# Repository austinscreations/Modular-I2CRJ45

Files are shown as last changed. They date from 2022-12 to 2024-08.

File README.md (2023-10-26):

# Modular-I2CRJ45
an oxrs compatible I2CRJ45 board in a modular format

2023-10-25 version 220 was created to fix p fet issue
also updated JLCPCB PCBa files for the modular I2CRJ45 and port PWR extention

this baord is 2 layers

port PWR is 2 layers

port PWR extention is a remote switch that allows you to turn ports on and off. the use of a 1.25mm jst cable could eb used instead, simply with pin 5 being GND connect the others to this and a port will be ON

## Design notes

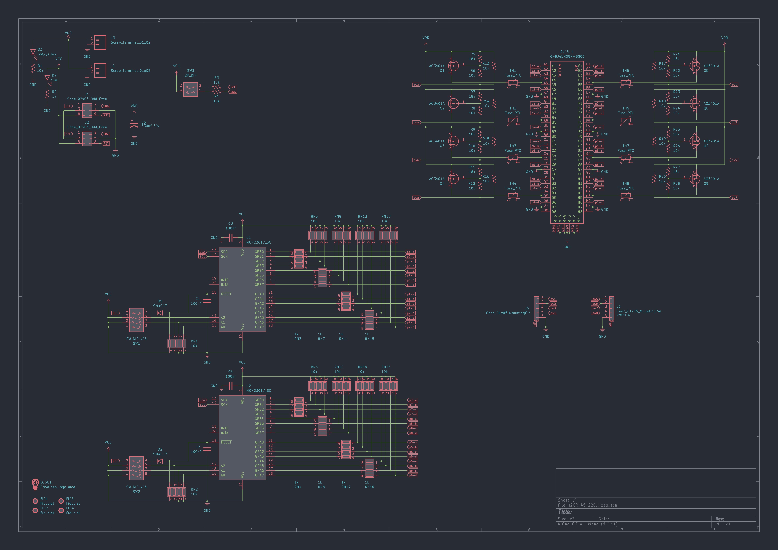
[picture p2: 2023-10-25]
rev 2_2/I2CRJ45 220 modular schematic.jpg

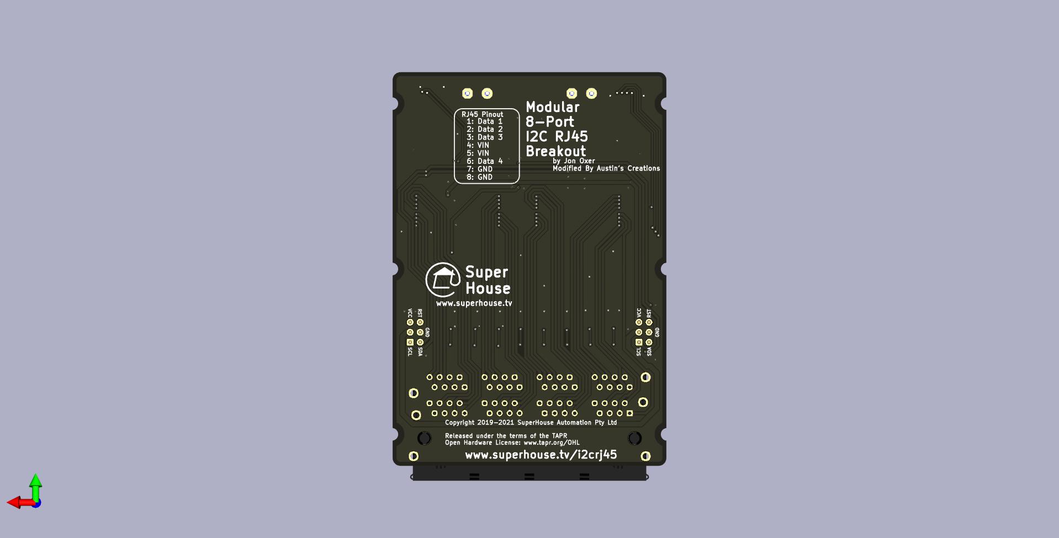
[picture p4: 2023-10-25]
rev 2_2/I2CRJ45 220 modular bottom.jpg

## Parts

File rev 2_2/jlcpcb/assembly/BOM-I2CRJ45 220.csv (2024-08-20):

Comment | Designator | Footprint | LCSC
Conn_02x03_Odd_Even | J1,J2 | IDC-Header_2x03_P2.54mm_Vertical | C132438
100nf | C1,C2,C3,C4 | C_0603_1608Metric | C14663
AO3401A | Q1,Q2,Q3,Q4,Q5,Q6,Q7,Q8 | SOT-23 | C15127
1k | RN11,RN12,RN15,RN16,RN3,RN4,RN7,RN8 | R_Array_Convex_4x0603 | C20197
1k | R2 | R_0603_1608Metric | C21190
Conn_01x05_MountingPin | J5,J6 | JST_GH_SM05B-GHS-TB_1x05-1MP_P1.25mm_Horizontal | C225114
10k | R1,R10,R12,R13,R14,R15,R16,R17,R18,R19,R20,R22,R24,R26,R28,R3,R4,R6,R8 | R_0603_1608Metric | C25804
18k | R11,R21,R23,R25,R27,R5,R7,R9 | R_0603_1608Metric | C25810
2P_DIP | SW3 | 2P_DIP | C2758181
SW_DIP_x04 | SW1,SW2 | 4P_DIP | C2758183
330uf 50v | C5 | CP_Elec_10x10 | C2895745
10k | RN1,RN10,RN13,RN14,RN17,RN18,RN2,RN5,RN6,RN9 | R_Array_Convex_4x0603 | C29718
Screw_Terminal_01x02 | J3,J4 | 2pinblock | C3703
R-RJ45R08P-8000 | RJ45-1 | R-RJ45R08P-8000 | C386760
MCP23017_SO | U1,U2 | SOIC-28W_7.5x17.9mm_P1.27mm | C47023
SM4007 | D1,D2 | D_SOD-123F | C64898
yellow | D3 | LED_0603_1608Metric | C72038
red | D4 | LED_0603_1608Metric | C2286
Fuse_PTC | TH1,TH2,TH3,TH4,TH5,TH6,TH7,TH8 | R_0603_1608Metric | C883087

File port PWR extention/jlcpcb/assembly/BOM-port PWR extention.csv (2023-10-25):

Comment | Designator | Footprint | LCSC
Conn_01x05_MountingPin | J5,J6 | JST_GH_SM05B-GHS-TB_1x05-1MP_P1.25mm_Horizontal | C225114
SW_DIP_x04 | SW1,SW2 | 4P_DIP | C2758183

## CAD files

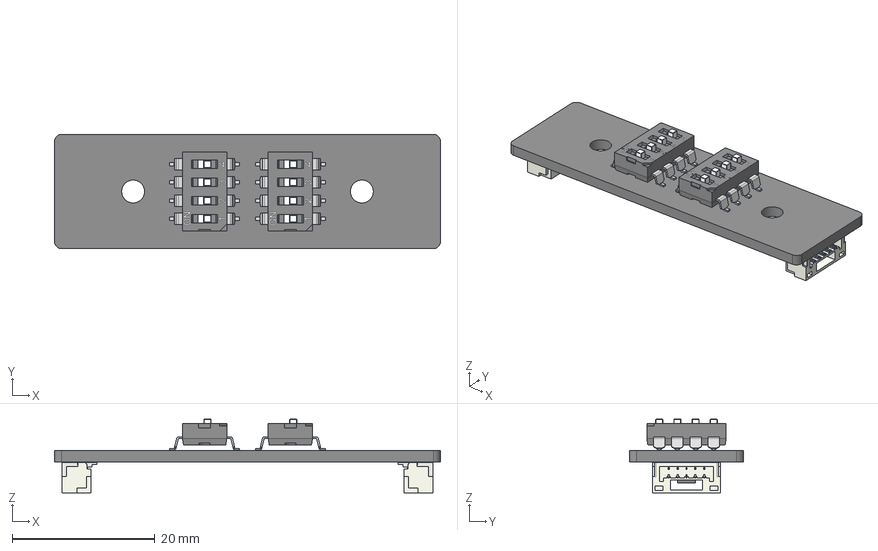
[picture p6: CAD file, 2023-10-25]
port PWR extention/port PWR extention.step
54.0 x 16.0 x 10.3 mm
_autosave-port PWR extention PCB

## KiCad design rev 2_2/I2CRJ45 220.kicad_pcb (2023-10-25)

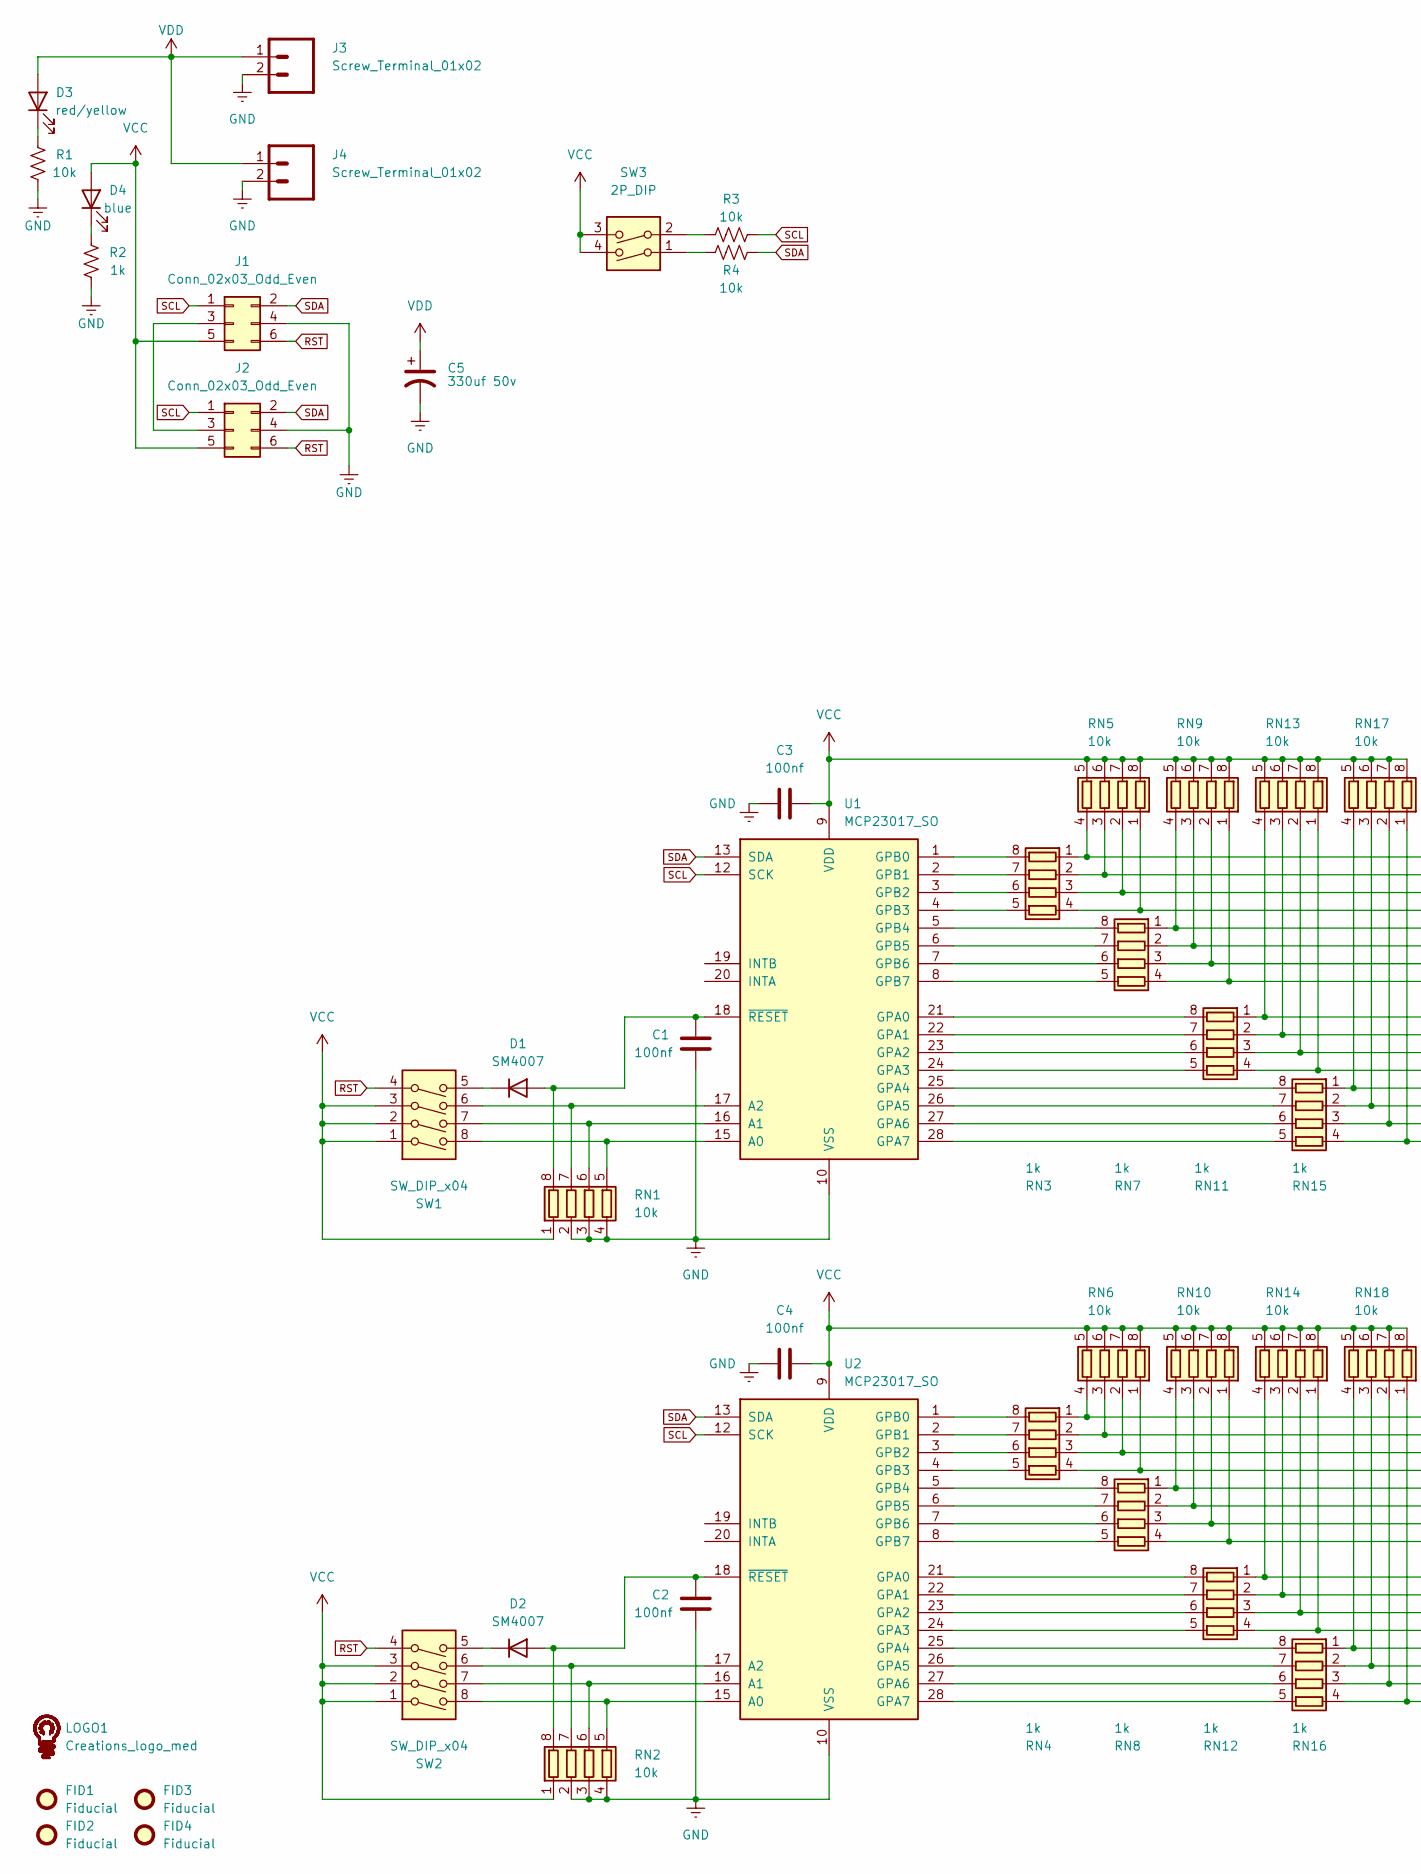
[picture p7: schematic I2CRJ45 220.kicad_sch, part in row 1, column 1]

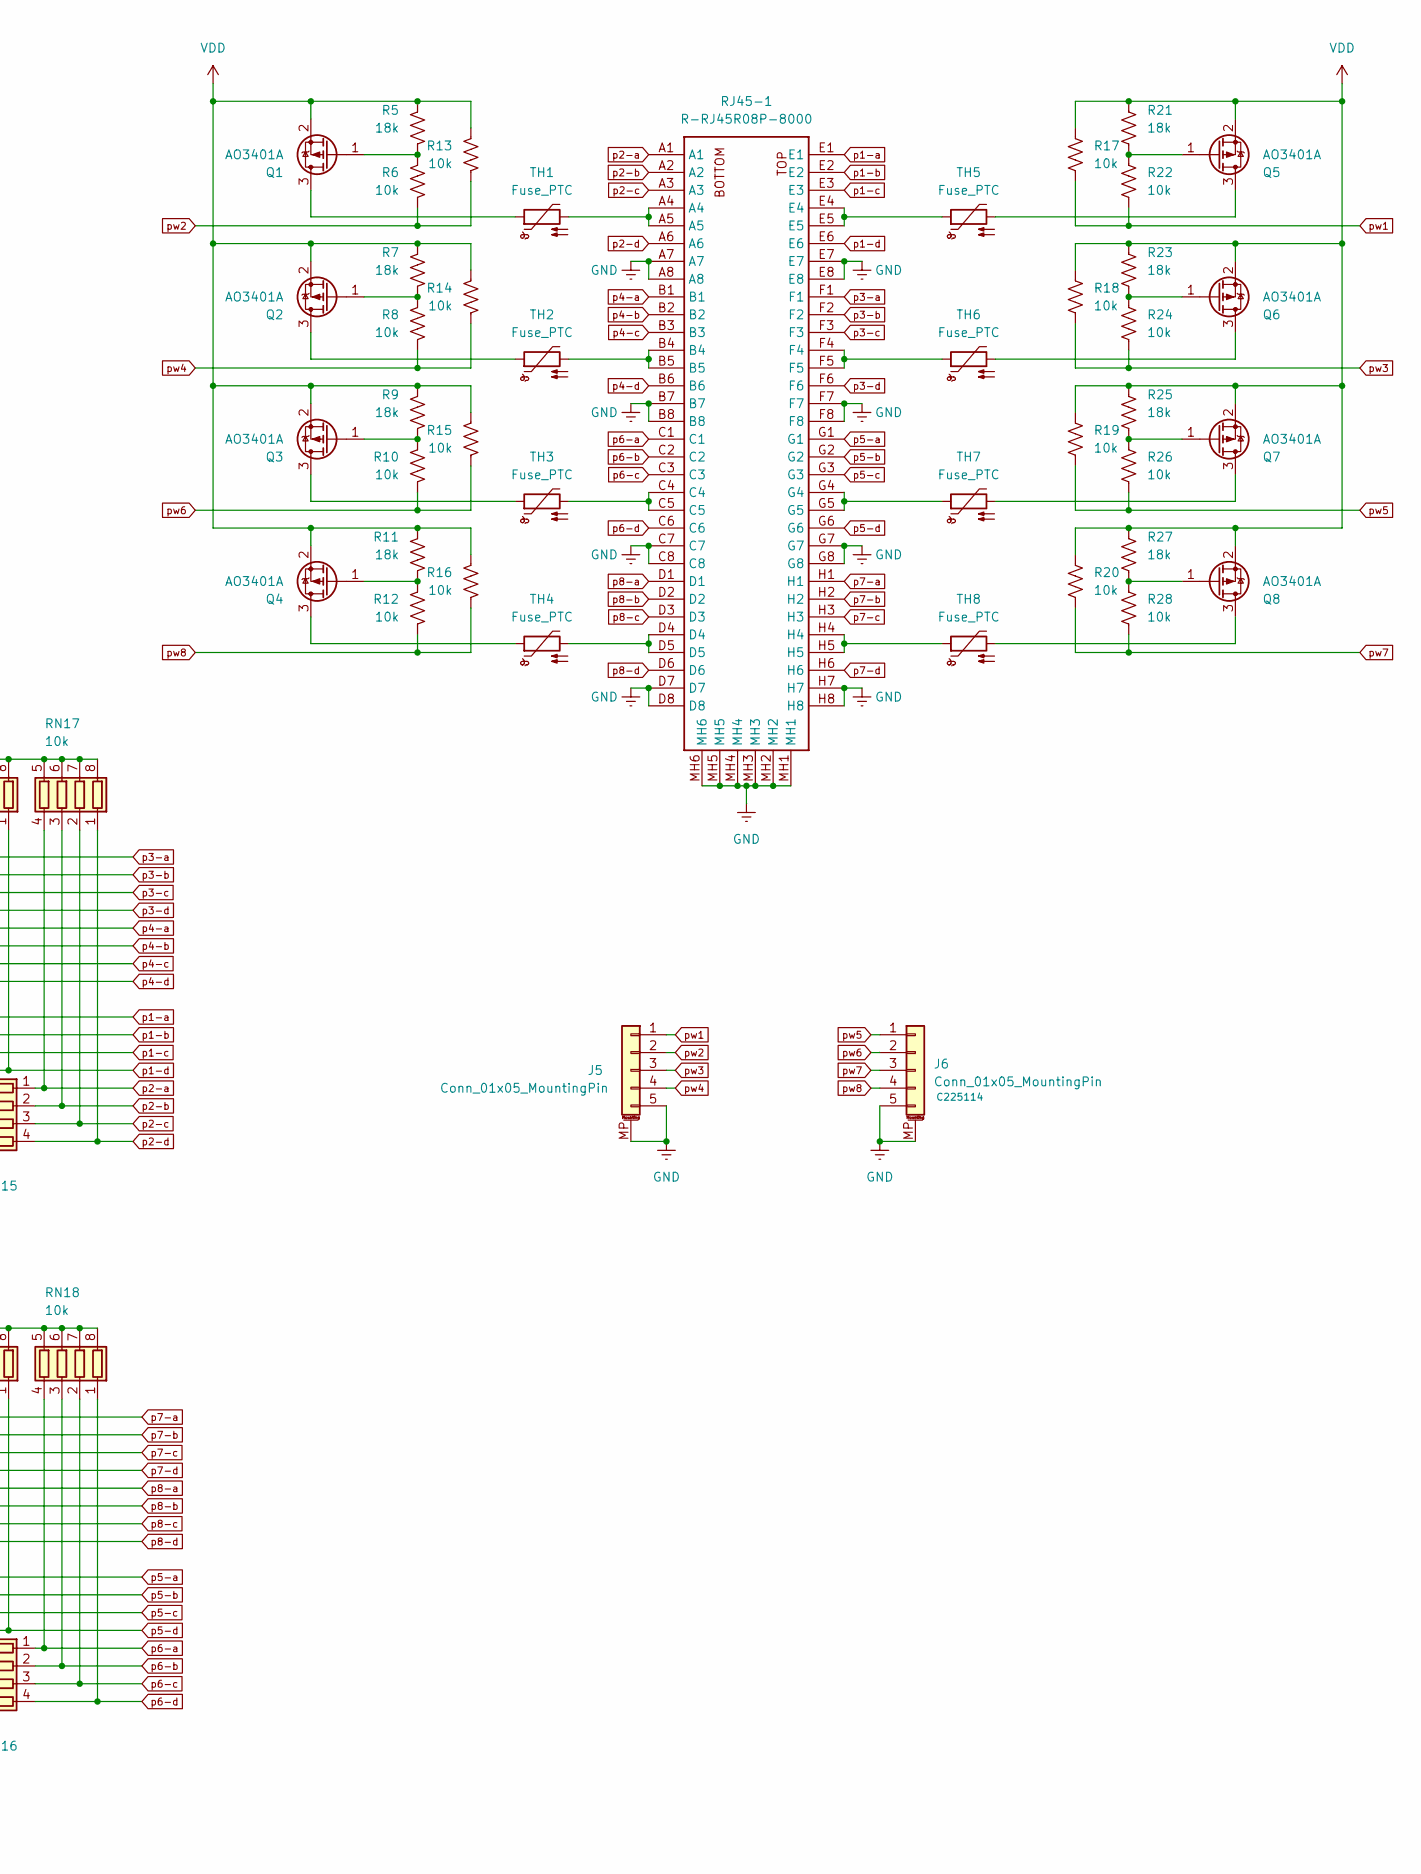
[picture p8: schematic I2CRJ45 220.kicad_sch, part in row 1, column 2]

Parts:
C1, C2, C3, C4: 100nf; C_0603_1608Metric; LCSC C14663
C5: 330uf 50v; CP_Elec_10x10; LCSC C2895745
D1, D2: SM4007; D_SOD-123F; LCSC C64898
D3: red/yellow; LED_0603_1608Metric; LCSC C72038
D4: blue; LED_0603_1608Metric; LCSC C72041
FID1, FID2, FID3, FID4: Fiducial; Fiducial_1mm_Mask2mm
J1, J2: Conn_02x03_Odd_Even; IDC-Header_2x03_P2.54mm_Vertical; LCSC C132438
J3, J4: Screw_Terminal_01x02; 2pinblock; LCSC C3703
J5, J6: Conn_01x05_MountingPin; JST_GH_SM05B-GHS-TB_1x05-1MP_P1.25mm_Horizontal; LCSC C225114
LOGO1: Creations_logo_med; Creations logo med
Q1, Q2, Q3, Q4, Q5, Q6, Q7, Q8: AO3401A; SOT-23; LCSC C15127
R1, R3, R4, R6, R8, R10, R12, R13, R14, R15, R16, R17, R18, R19, R20, R22, R24, R26, R28: 10k; R_0603_1608Metric; LCSC C25804
R2: 1k; R_0603_1608Metric; LCSC C21190
R5, R7, R9, R11, R21, R23, R25, R27: 18k; R_0603_1608Metric; LCSC C25810
RJ45-1: R-RJ45R08P-8000; LCSC C386760
RN1, RN2, RN5, RN6, RN9, RN10, RN13, RN14, RN17, RN18: 10k; R_Array_Convex_4x0603; LCSC C29718
RN3, RN4, RN7, RN8, RN11, RN12, RN15, RN16: 1k; R_Array_Convex_4x0603; LCSC C20197
SW1, SW2: SW_DIP_x04; 4P_DIP; LCSC C2758183
SW3: 2P_DIP; LCSC C2758181
TH1, TH2, TH3, TH4, TH5, TH6, TH7, TH8: Fuse_PTC; R_0603_1608Metric; LCSC C883087
U1, U2: MCP23017_SO; SOIC-28W_7.5x17.9mm_P1.27mm; LCSC C47023

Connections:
GNDREF: C1.2, C2.2, C3.1, C4.1, C5.2, J1.4, J2.4, J3.2, J4.2, J5.5, J5.MP (MountPin), J6.5, J6.MP (MountPin), R1.2, R2.2, RJ45-1.A7, RJ45-1.A8, RJ45-1.B7, RJ45-1.B8, RJ45-1.C7, RJ45-1.C8, RJ45-1.D7, RJ45-1.D8, RJ45-1.E7, RJ45-1.E8, RJ45-1.F7, RJ45-1.F8, RJ45-1.G7, RJ45-1.G8, RJ45-1.H7, RJ45-1.H8, RJ45-1.MH1, RJ45-1.MH2, RJ45-1.MH3, RJ45-1.MH4, RJ45-1.MH5, RJ45-1.MH6, RN1.2 (R2.1), RN1.3 (R3.1), RN1.4 (R4.1), RN2.2 (R2.1), RN2.3 (R3.1), RN2.4 (R4.1), U1.10 (VSS), U2.10 (VSS)
unnamed: C1.1, D1.2 (A), RN1.8 (R1.2), U1.18 (~RESET)
unnamed: C2.1, D2.2 (A), RN2.8 (R1.2), U2.18 (~RESET)
unnamed: D1.1 (K), SW1.5
unnamed: D2.1 (K), SW2.5
unnamed: D3.1 (K), R1.1
unnamed: D4.1 (K), R2.1
unnamed: J1.3, J2.3
unnamed: Q1.1 (G), R5.2, R6.1
unnamed: Q2.1 (G), R7.2, R8.1
unnamed: Q3.1 (G), R9.2, R10.1
unnamed: Q4.1 (G), R11.2, R12.1
unnamed: Q5.1 (G), R21.2, R22.1
unnamed: Q6.1 (G), R23.2, R24.1
unnamed: Q7.1 (G), R25.2, R26.1
unnamed: Q8.1 (G), R27.2, R28.1
unnamed: R3.1, SW3.2
unnamed: R4.1, SW3.1
unnamed: RJ45-1.A4, RJ45-1.A5, TH1.2
unnamed: RJ45-1.B4, RJ45-1.B5, TH2.2
unnamed: RJ45-1.C4, RJ45-1.C5, TH3.2
unnamed: RJ45-1.D4, RJ45-1.D5, TH4.2
unnamed: RJ45-1.E4, RJ45-1.E5, TH5.1
unnamed: RJ45-1.F4, RJ45-1.F5, TH6.1
unnamed: RJ45-1.G4, RJ45-1.G5, TH7.1
unnamed: RJ45-1.H4, RJ45-1.H5, TH8.1
unnamed: RN1.5 (R4.2), SW1.8, U1.15 (A0)
unnamed: RN1.6 (R3.2), SW1.7, U1.16 (A1)
unnamed: RN1.7 (R2.2), SW1.6, U1.17 (A2)
unnamed: RN2.5 (R4.2), SW2.8, U2.15 (A0)
unnamed: RN2.6 (R3.2), SW2.7, U2.16 (A1)
unnamed: RN2.7 (R2.2), SW2.6, U2.17 (A2)
unnamed: RN3.5 (R4.2), U1.4 (GPB3)
unnamed: RN3.6 (R3.2), U1.3 (GPB2)
unnamed: RN3.7 (R2.2), U1.2 (GPB1)
unnamed: RN3.8 (R1.2), U1.1 (GPB0)
unnamed: RN4.5 (R4.2), U2.4 (GPB3)
unnamed: RN4.6 (R3.2), U2.3 (GPB2)
unnamed: RN4.7 (R2.2), U2.2 (GPB1)
unnamed: RN4.8 (R1.2), U2.1 (GPB0)
unnamed: RN7.5 (R4.2), U1.8 (GPB7)
unnamed: RN7.6 (R3.2), U1.7 (GPB6)
unnamed: RN7.7 (R2.2), U1.6 (GPB5)
unnamed: RN7.8 (R1.2), U1.5 (GPB4)
unnamed: RN8.5 (R4.2), U2.8 (GPB7)
unnamed: RN8.6 (R3.2), U2.7 (GPB6)
unnamed: RN8.7 (R2.2), U2.6 (GPB5)
unnamed: RN8.8 (R1.2), U2.5 (GPB4)
unnamed: RN11.5 (R4.2), U1.24 (GPA3)
unnamed: RN11.6 (R3.2), U1.23 (GPA2)
unnamed: RN11.7 (R2.2), U1.22 (GPA1)
unnamed: RN11.8 (R1.2), U1.21 (GPA0)
unnamed: RN12.5 (R4.2), U2.24 (GPA3)
unnamed: RN12.6 (R3.2), U2.23 (GPA2)
unnamed: RN12.7 (R2.2), U2.22 (GPA1)
unnamed: RN12.8 (R1.2), U2.21 (GPA0)
unnamed: RN15.5 (R4.2), U1.28 (GPA7)
unnamed: RN15.6 (R3.2), U1.27 (GPA6)
unnamed: RN15.7 (R2.2), U1.26 (GPA5)
unnamed: RN15.8 (R1.2), U1.25 (GPA4)
unnamed: RN16.5 (R4.2), U2.28 (GPA7)
unnamed: RN16.6 (R3.2), U2.27 (GPA6)
unnamed: RN16.7 (R2.2), U2.26 (GPA5)
unnamed: RN16.8 (R1.2), U2.25 (GPA4)
unnamed: Q1.3 (D), TH1.1
unnamed: Q2.3 (D), TH2.1
unnamed: Q3.3 (D), TH3.1
unnamed: Q4.3 (D), TH4.1
unnamed: Q5.3 (D), TH5.2
unnamed: Q6.3 (D), TH6.2
unnamed: Q7.3 (D), TH7.2
unnamed: Q8.3 (D), TH8.2
RST: J1.6, J2.6, SW1.4, SW2.4
SCL: J1.1, J2.1, R3.2, U1.12 (SCK), U2.12 (SCK)
SDA: J1.2, J2.2, R4.2, U1.13 (SDA), U2.13 (SDA)
VCC: C3.2, C4.2, D4.2 (A), J1.5, J2.5, RN1.1 (R1.1), RN2.1 (R1.1), RN5.5 (R4.2), RN5.6 (R3.2), RN5.7 (R2.2), RN5.8 (R1.2), RN6.5 (R4.2), RN6.6 (R3.2), RN6.7 (R2.2), RN6.8 (R1.2), RN9.5 (R4.2), RN9.6 (R3.2), RN9.7 (R2.2), RN9.8 (R1.2), RN10.5 (R4.2), RN10.6 (R3.2), RN10.7 (R2.2), RN10.8 (R1.2), RN13.5 (R4.2), RN13.6 (R3.2), RN13.7 (R2.2), RN13.8 (R1.2), RN14.5 (R4.2), RN14.6 (R3.2), RN14.7 (R2.2), RN14.8 (R1.2), RN17.5 (R4.2), RN17.6 (R3.2), RN17.7 (R2.2), RN17.8 (R1.2), RN18.5 (R4.2), RN18.6 (R3.2), RN18.7 (R2.2), RN18.8 (R1.2), SW1.1, SW1.2, SW1.3, SW2.1, SW2.2, SW2.3, SW3.3, SW3.4, U1.9 (VDD), U2.9 (VDD)
VDD: C5.1, D3.2 (A), J3.1, J4.1, Q1.2 (S), Q2.2 (S), Q3.2 (S), Q4.2 (S), Q5.2 (S), Q6.2 (S), Q7.2 (S), Q8.2 (S), R5.1, R7.1, R9.1, R11.1, R13.1, R14.1, R15.1, R16.1, R17.1, R18.1, R19.1, R20.1, R21.1, R23.1, R25.1, R27.1
p1-a: RJ45-1.E1, RN11.1 (R1.1), RN13.4 (R4.1)
p1-b: RJ45-1.E2, RN11.2 (R2.1), RN13.3 (R3.1)
p1-c: RJ45-1.E3, RN11.3 (R3.1), RN13.2 (R2.1)
p1-d: RJ45-1.E6, RN11.4 (R4.1), RN13.1 (R1.1)
p2-a: RJ45-1.A1, RN15.1 (R1.1), RN17.4 (R4.1)
p2-b: RJ45-1.A2, RN15.2 (R2.1), RN17.3 (R3.1)
p2-c: RJ45-1.A3, RN15.3 (R3.1), RN17.2 (R2.1)
p2-d: RJ45-1.A6, RN15.4 (R4.1), RN17.1 (R1.1)
p3-a: RJ45-1.F1, RN3.1 (R1.1), RN5.4 (R4.1)
p3-b: RJ45-1.F2, RN3.2 (R2.1), RN5.3 (R3.1)
p3-c: RJ45-1.F3, RN3.3 (R3.1), RN5.2 (R2.1)
p3-d: RJ45-1.F6, RN3.4 (R4.1), RN5.1 (R1.1)
p4-a: RJ45-1.B1, RN7.1 (R1.1), RN9.4 (R4.1)
p4-b: RJ45-1.B2, RN7.2 (R2.1), RN9.3 (R3.1)
p4-c: RJ45-1.B3, RN7.3 (R3.1), RN9.2 (R2.1)
p4-d: RJ45-1.B6, RN7.4 (R4.1), RN9.1 (R1.1)
p5-a: RJ45-1.G1, RN12.1 (R1.1), RN14.4 (R4.1)
p5-b: RJ45-1.G2, RN12.2 (R2.1), RN14.3 (R3.1)
p5-c: RJ45-1.G3, RN12.3 (R3.1), RN14.2 (R2.1)
p5-d: RJ45-1.G6, RN12.4 (R4.1), RN14.1 (R1.1)
p6-a: RJ45-1.C1, RN16.1 (R1.1), RN18.4 (R4.1)
p6-b: RJ45-1.C2, RN16.2 (R2.1), RN18.3 (R3.1)
p6-c: RJ45-1.C3, RN16.3 (R3.1), RN18.2 (R2.1)
p6-d: RJ45-1.C6, RN16.4 (R4.1), RN18.1 (R1.1)
p7-a: RJ45-1.H1, RN4.1 (R1.1), RN6.4 (R4.1)
p7-b: RJ45-1.H2, RN4.2 (R2.1), RN6.3 (R3.1)
p7-c: RJ45-1.H3, RN4.3 (R3.1), RN6.2 (R2.1)
p7-d: RJ45-1.H6, RN4.4 (R4.1), RN6.1 (R1.1)
p8-a: RJ45-1.D1, RN8.1 (R1.1), RN10.4 (R4.1)
p8-b: RJ45-1.D2, RN8.2 (R2.1), RN10.3 (R3.1)
p8-c: RJ45-1.D3, RN8.3 (R3.1), RN10.2 (R2.1)
p8-d: RJ45-1.D6, RN8.4 (R4.1), RN10.1 (R1.1)
pw1: J5.1, R17.2, R22.2
pw2: J5.2, R6.2, R13.2
pw3: J5.3, R18.2, R24.2
pw4: J5.4, R8.2, R14.2
pw5: J6.1, R19.2, R26.2
pw6: J6.2, R10.2, R15.2
pw7: J6.3, R20.2, R28.2
pw8: J6.4, R12.2, R16.2

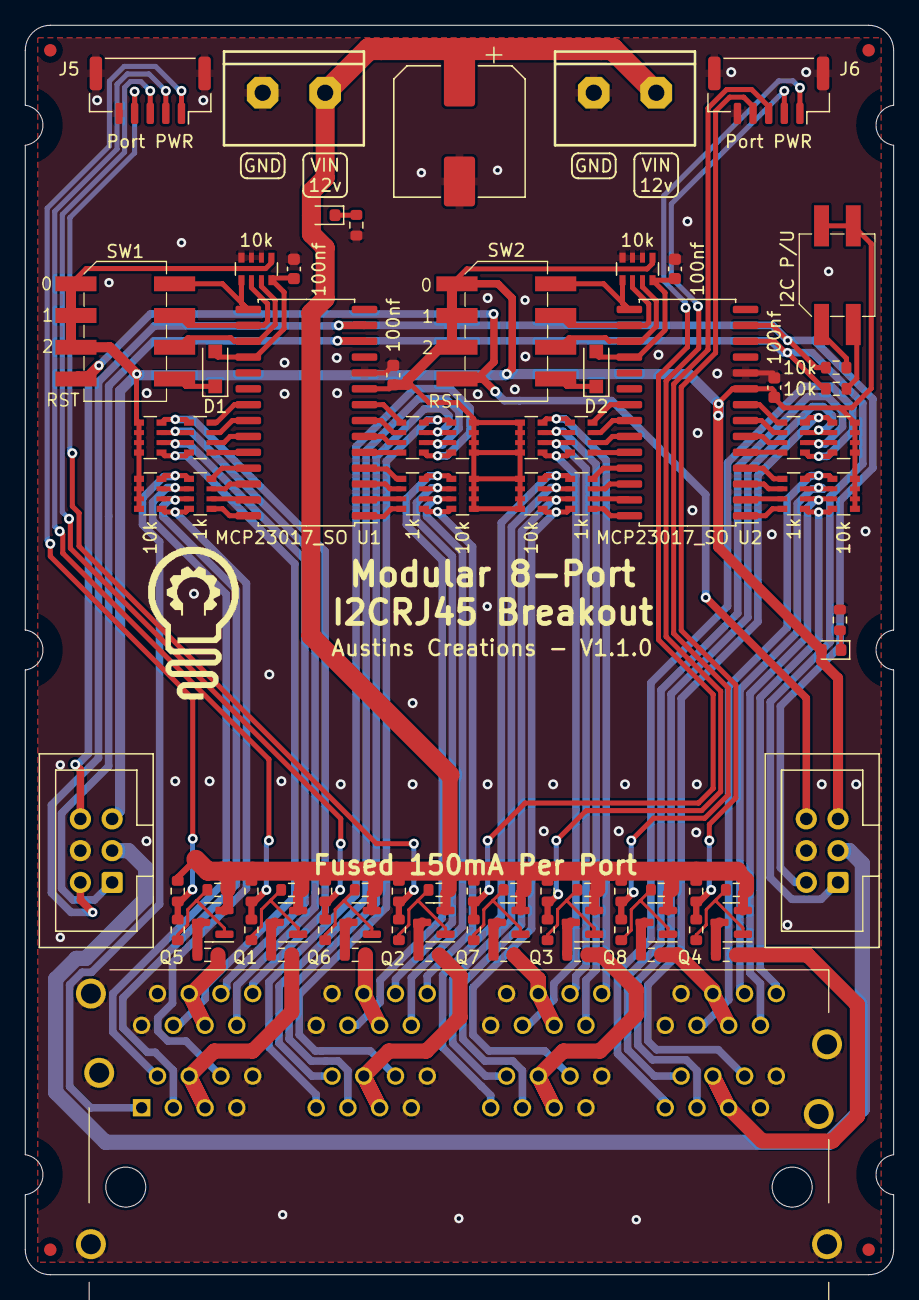
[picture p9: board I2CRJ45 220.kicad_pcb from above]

Board: 2 copper layers, 69.5 x 100.0 mm, 88 parts (0 on the bottom side), 117 nets.

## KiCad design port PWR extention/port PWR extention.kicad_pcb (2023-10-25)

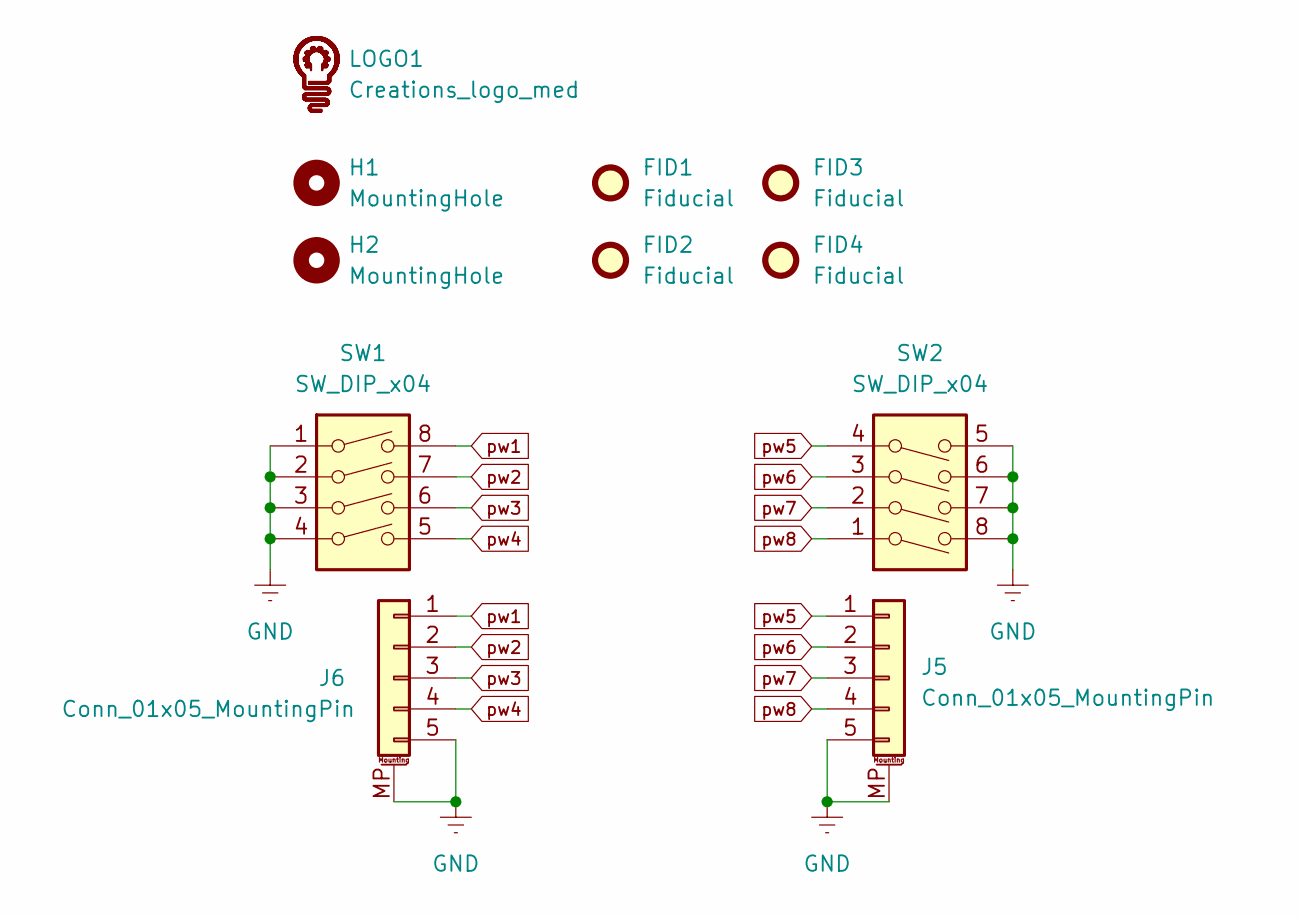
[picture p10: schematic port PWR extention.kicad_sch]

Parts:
FID1, FID2, FID3, FID4: Fiducial; Fiducial_1mm_Mask2mm
H1, H2: MountingHole; MountingHole_3.2mm_M3
J5, J6: Conn_01x05_MountingPin; JST_GH_SM05B-GHS-TB_1x05-1MP_P1.25mm_Horizontal; LCSC C225114
LOGO1: Creations_logo_med; Creations logo med
SW1, SW2: SW_DIP_x04; 4P_DIP; LCSC C2758183

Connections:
GNDREF: J5.5, J5.MP (MountPin), J6.5, J6.MP (MountPin), SW1.1, SW1.2, SW1.3, SW1.4, SW2.5, SW2.6, SW2.7, SW2.8
pw1: J6.1, SW1.8
pw2: J6.2, SW1.7
pw3: J6.3, SW1.6
pw4: J6.4, SW1.5
pw5: J5.1, SW2.4
pw6: J5.2, SW2.3
pw7: J5.3, SW2.2
pw8: J5.4, SW2.1

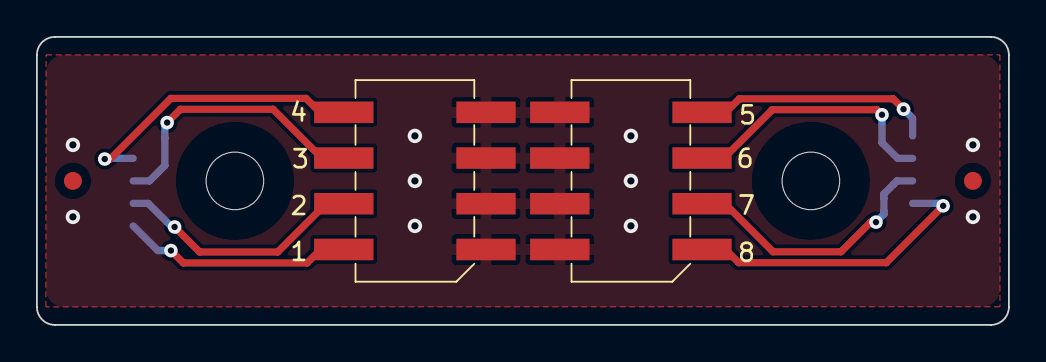
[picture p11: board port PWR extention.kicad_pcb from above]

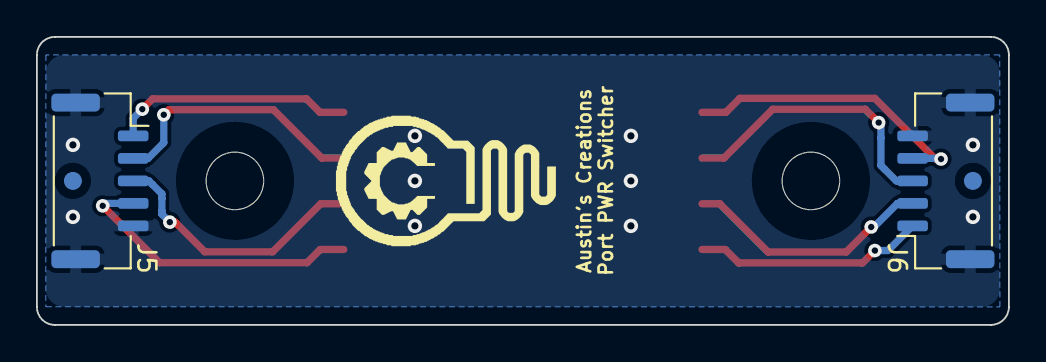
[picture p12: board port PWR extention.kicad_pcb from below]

Board: 2 copper layers, 54.0 x 16.0 mm, 11 parts (5 on the bottom side), 9 nets.

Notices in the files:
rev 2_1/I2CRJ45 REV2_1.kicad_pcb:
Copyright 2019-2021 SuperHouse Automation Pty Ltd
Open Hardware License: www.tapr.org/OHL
